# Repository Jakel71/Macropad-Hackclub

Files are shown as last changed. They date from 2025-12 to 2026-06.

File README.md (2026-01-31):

# Macropad-Hackclub
This is an Macro pad with 16 Buttons with background lighting. Its meant for simplicity and an everyday use. This is the reason why it will have shortcuts for Windows 11. You could adjust the Container of the PCB so that the lights are looking out, but scince I never saw this kind of LED I don't know how big the hole has to be.



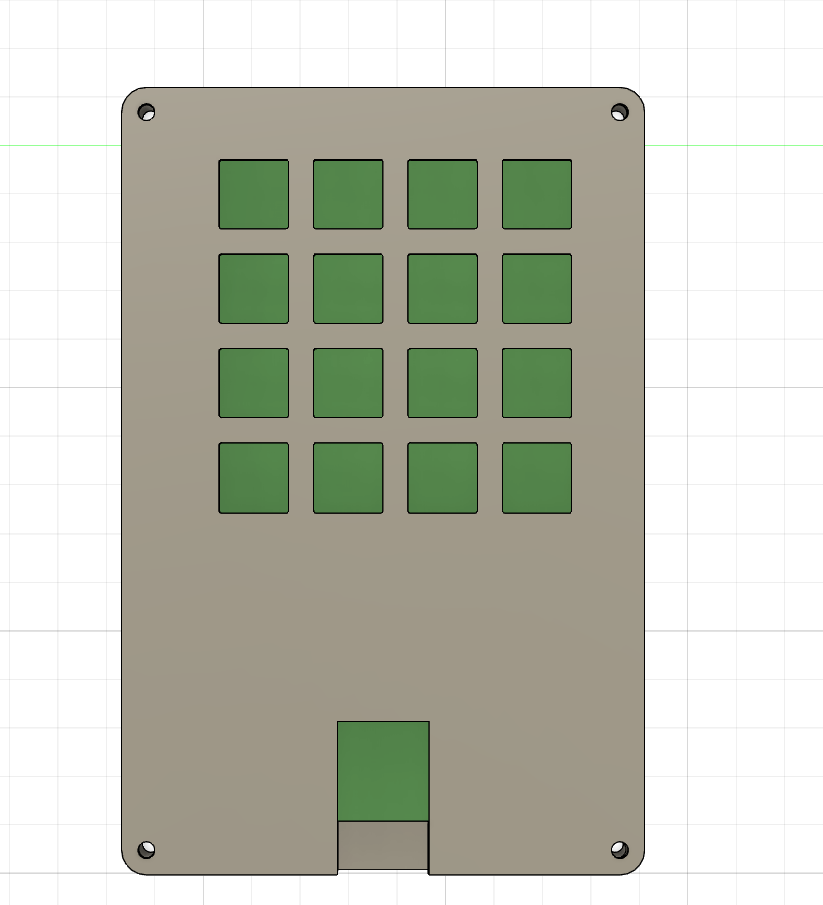
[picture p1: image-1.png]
over-all-box


In this picture you can see the Box in gray and the PCB in Green.

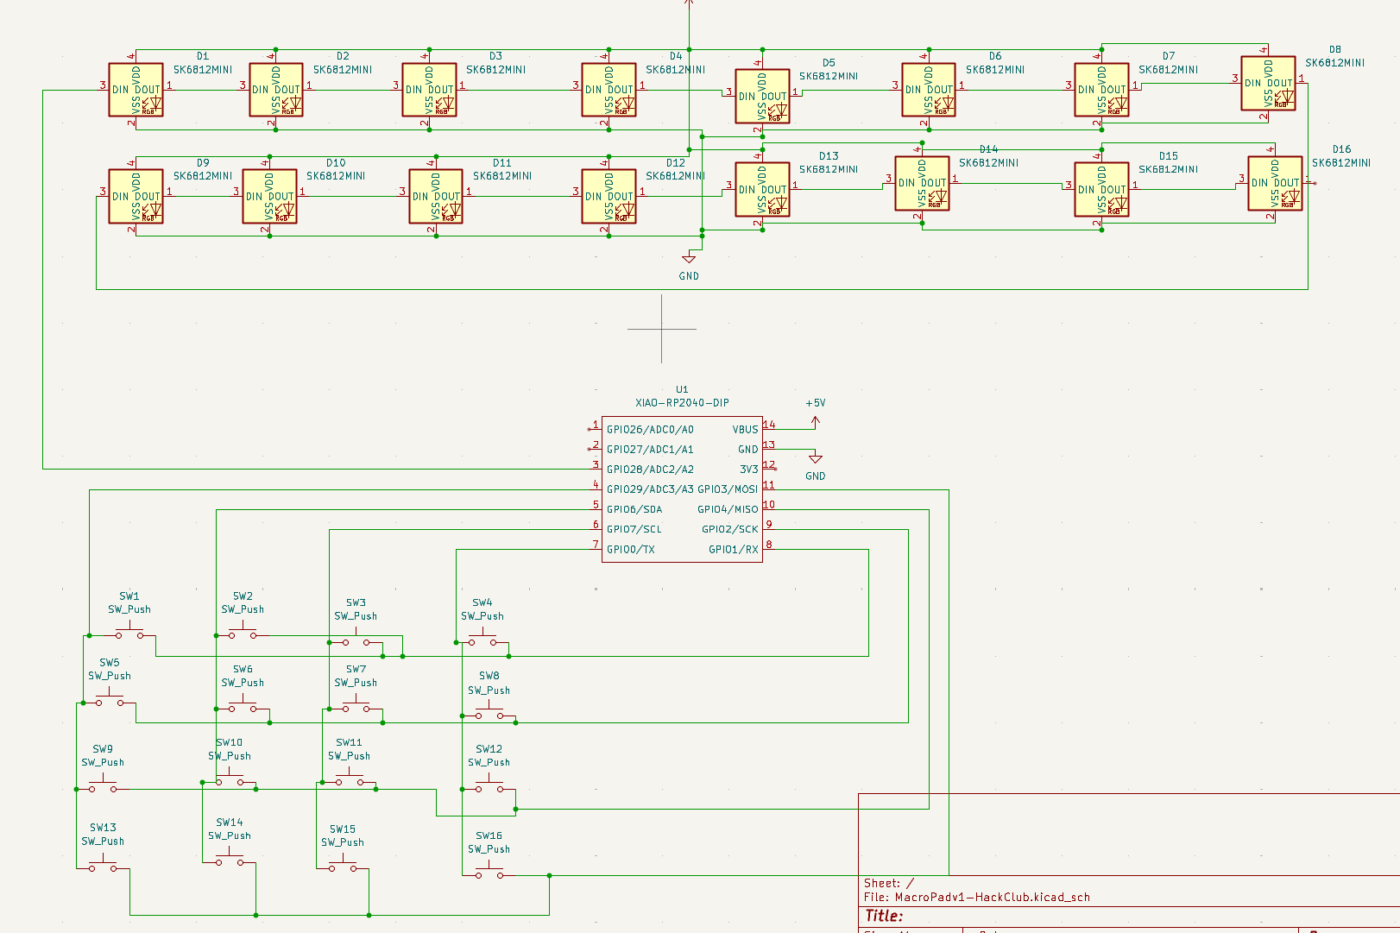
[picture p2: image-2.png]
shematics

Here you can see the shematics of th PCB. It could happen that the Analog pins won't allow Digitalinput, then you schould switsh to an other microcontroller (arduino/ESP) with more pins.

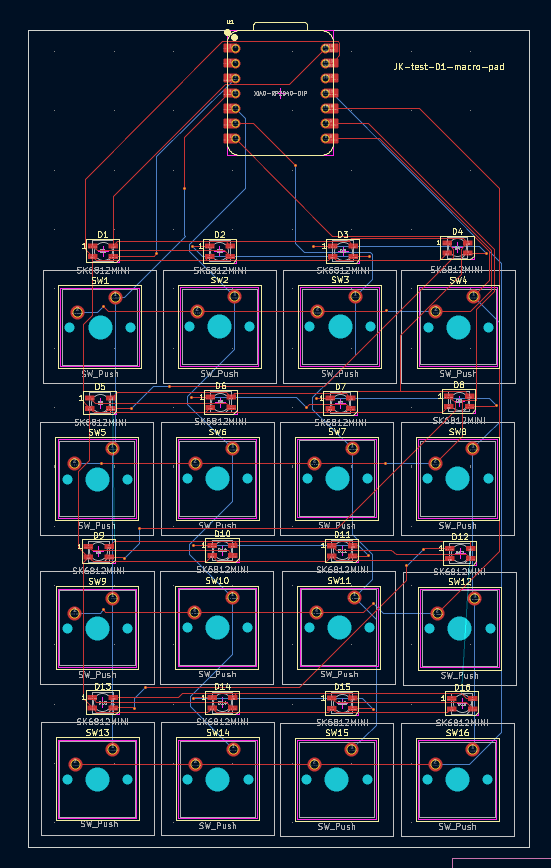
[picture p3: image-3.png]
PCB


Here you can see the PCB and all the components which you have to mount on it. The dimensions are 137x84.5mm this is more than the limit of 100mm in one dimension, but it would become very messy when you would pack it closer together.

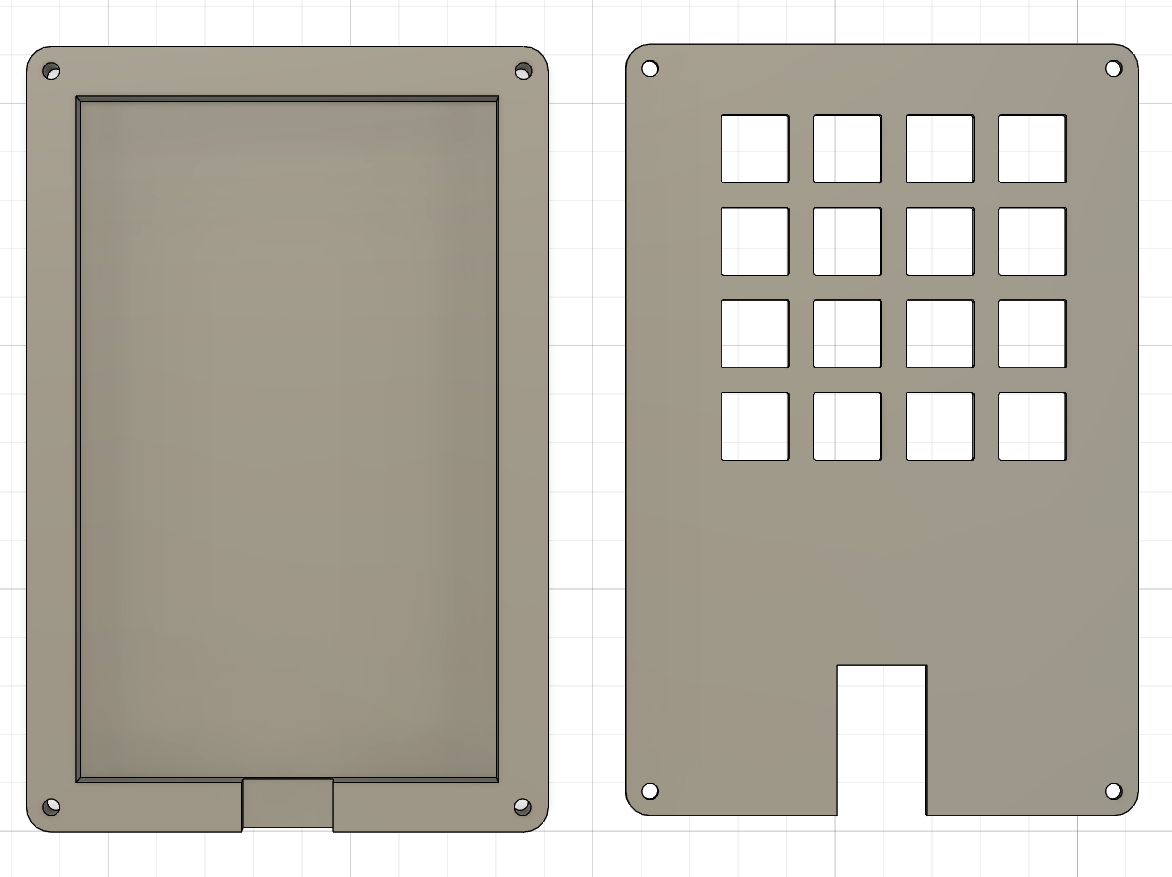
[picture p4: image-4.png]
caseparts

You can see here all the parts you need for the case just screew 4 screews in it and its ready to go.

BOM: (list of materials)
- 1 PCB
- 1 Case ( bittom + top part)
- M3x16mm screws
- M3x5mx4mm heatset inserts
- 16 Cherry MX 1 Keyboardbuttons
- 16 Keycaps
- 16 SK6812 MINI-E LEDs
- 1 Seeed XIAO RP2040

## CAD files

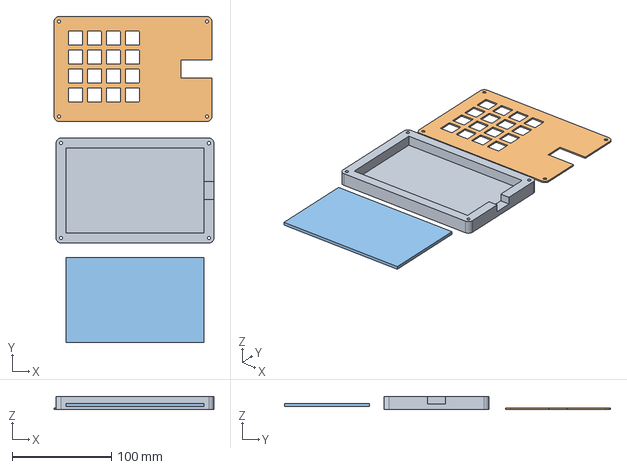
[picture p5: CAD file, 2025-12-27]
CAD/MacroPad-V_Hackclub v3.step
160.7 x 327.7 x 13.0 mm

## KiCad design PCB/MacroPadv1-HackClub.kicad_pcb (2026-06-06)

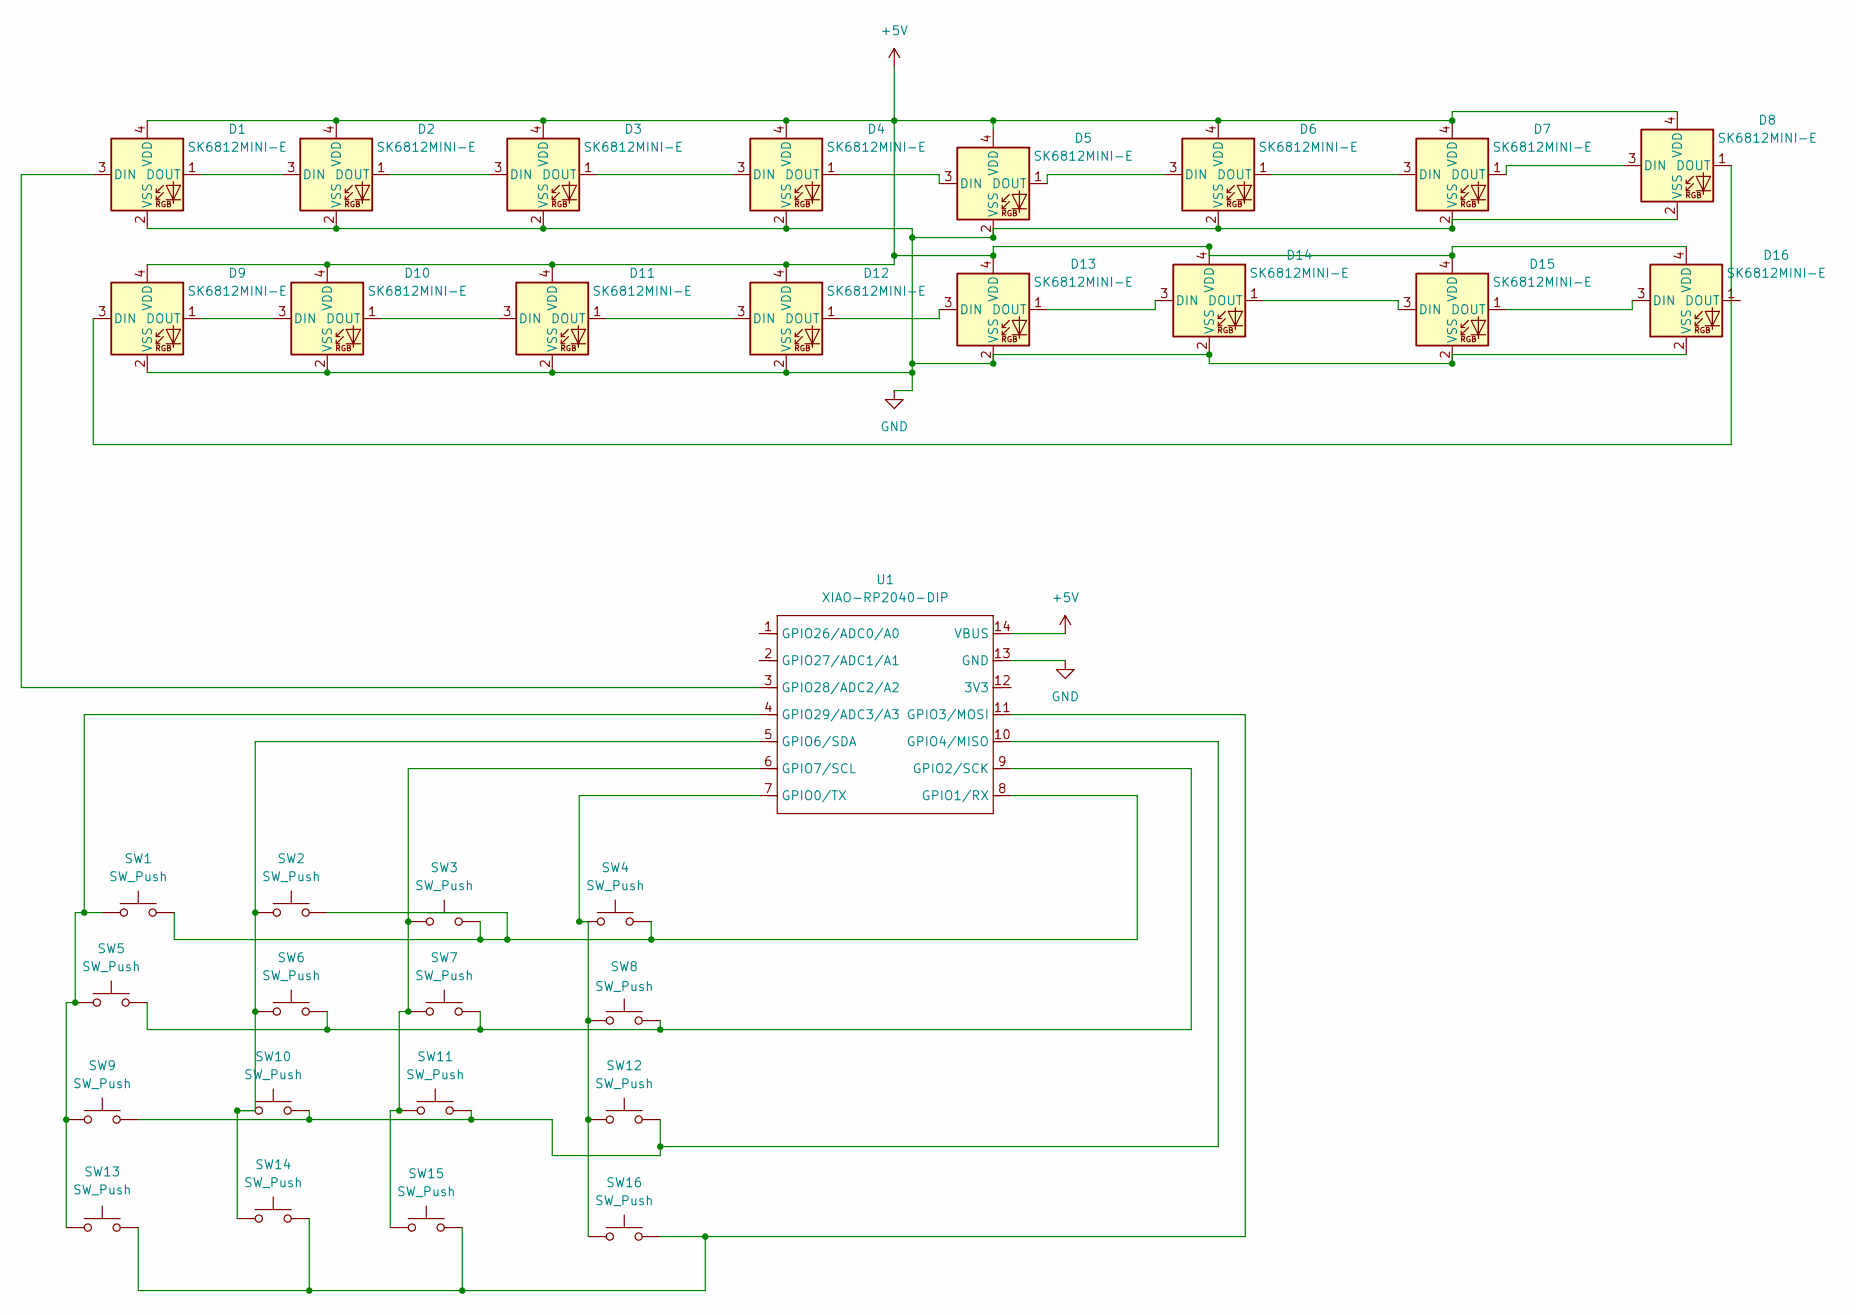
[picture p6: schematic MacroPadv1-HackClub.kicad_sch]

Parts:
D1, D2, D3, D4, D5, D6, D7, D8, D9, D10, D11, D12, D13, D14, D15, D16: SK6812MINI-E; MX_SK6812MINI-E
SW1, SW2, SW3, SW4, SW5, SW6, SW7, SW8, SW9, SW10, SW11, SW12, SW13, SW14, SW15, SW16: SW_Push; SW_Cherry_MX_1.00u_PCB
U1: XIAO-RP2040-DIP

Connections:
+5V: D1.4 (VDD), D2.4 (VDD), D3.4 (VDD), D4.4 (VDD), D5.4 (VDD), D6.4 (VDD), D7.4 (VDD), D8.4 (VDD), D9.4 (VDD), D10.4 (VDD), D11.4 (VDD), D12.4 (VDD), D13.4 (VDD), D14.4 (VDD), D15.4 (VDD), D16.4 (VDD), U1.14 (VBUS)
GND: D1.2 (VSS), D2.2 (VSS), D3.2 (VSS), D4.2 (VSS), D5.2 (VSS), D6.2 (VSS), D7.2 (VSS), D8.2 (VSS), D9.2 (VSS), D10.2 (VSS), D11.2 (VSS), D12.2 (VSS), D13.2 (VSS), D14.2 (VSS), D15.2 (VSS), D16.2 (VSS), U1.13 (GND)
unnamed: D1.3 (DIN), U1.3 (GPIO28/ADC2/A2)
unnamed: D1.1 (DOUT), D2.3 (DIN)
unnamed: D2.1 (DOUT), D3.3 (DIN)
unnamed: D3.1 (DOUT), D4.3 (DIN)
unnamed: D4.1 (DOUT), D5.3 (DIN)
unnamed: D5.1 (DOUT), D6.3 (DIN)
unnamed: D6.1 (DOUT), D7.3 (DIN)
unnamed: D7.1 (DOUT), D8.3 (DIN)
unnamed: D8.1 (DOUT), D9.3 (DIN)
unnamed: D9.1 (DOUT), D10.3 (DIN)
unnamed: D10.1 (DOUT), D11.3 (DIN)
unnamed: D11.1 (DOUT), D12.3 (DIN)
unnamed: D12.1 (DOUT), D13.3 (DIN)
unnamed: D13.1 (DOUT), D14.3 (DIN)
unnamed: D14.1 (DOUT), D15.3 (DIN)
unnamed: D15.1 (DOUT), D16.3 (DIN)
unnamed: SW4.1, SW8.1, SW12.1, SW16.1, U1.7 (GPIO0/TX)
unnamed: SW1.2, SW2.2, SW3.2, SW4.2, U1.8 (GPIO1/RX)
unnamed: SW5.2, SW6.2, SW7.2, SW8.2, U1.9 (GPIO2/SCK)
unnamed: SW13.2, SW14.2, SW15.2, SW16.2, U1.11 (GPIO3/MOSI)
unnamed: SW9.2, SW10.2, SW11.2, SW12.2, U1.10 (GPIO4/MISO)
unnamed: SW2.1, SW6.1, SW10.1, SW14.1, U1.5 (GPIO6/SDA)
unnamed: SW3.1, SW7.1, SW11.1, SW15.1, U1.6 (GPIO7/SCL)
unnamed: SW1.1, SW5.1, SW9.1, SW13.1, U1.4 (GPIO29/ADC3/A3)

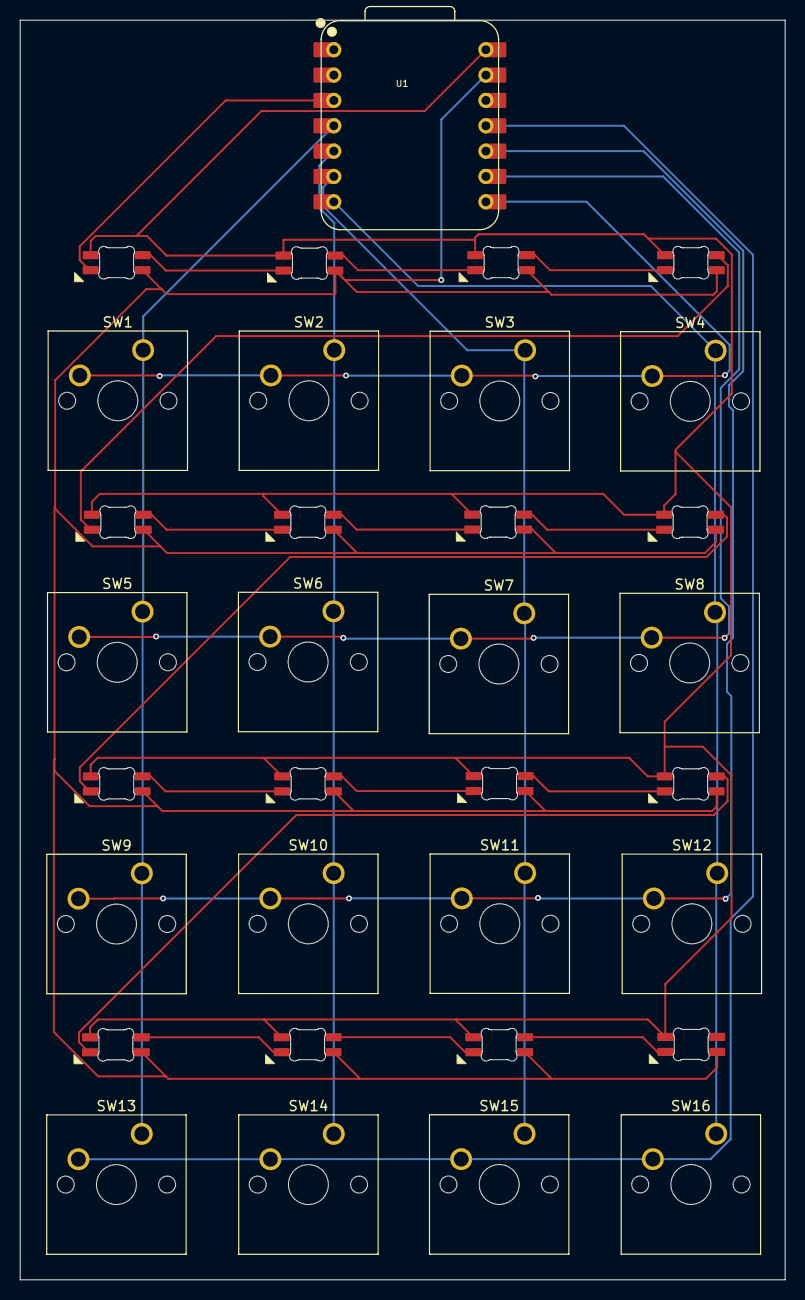
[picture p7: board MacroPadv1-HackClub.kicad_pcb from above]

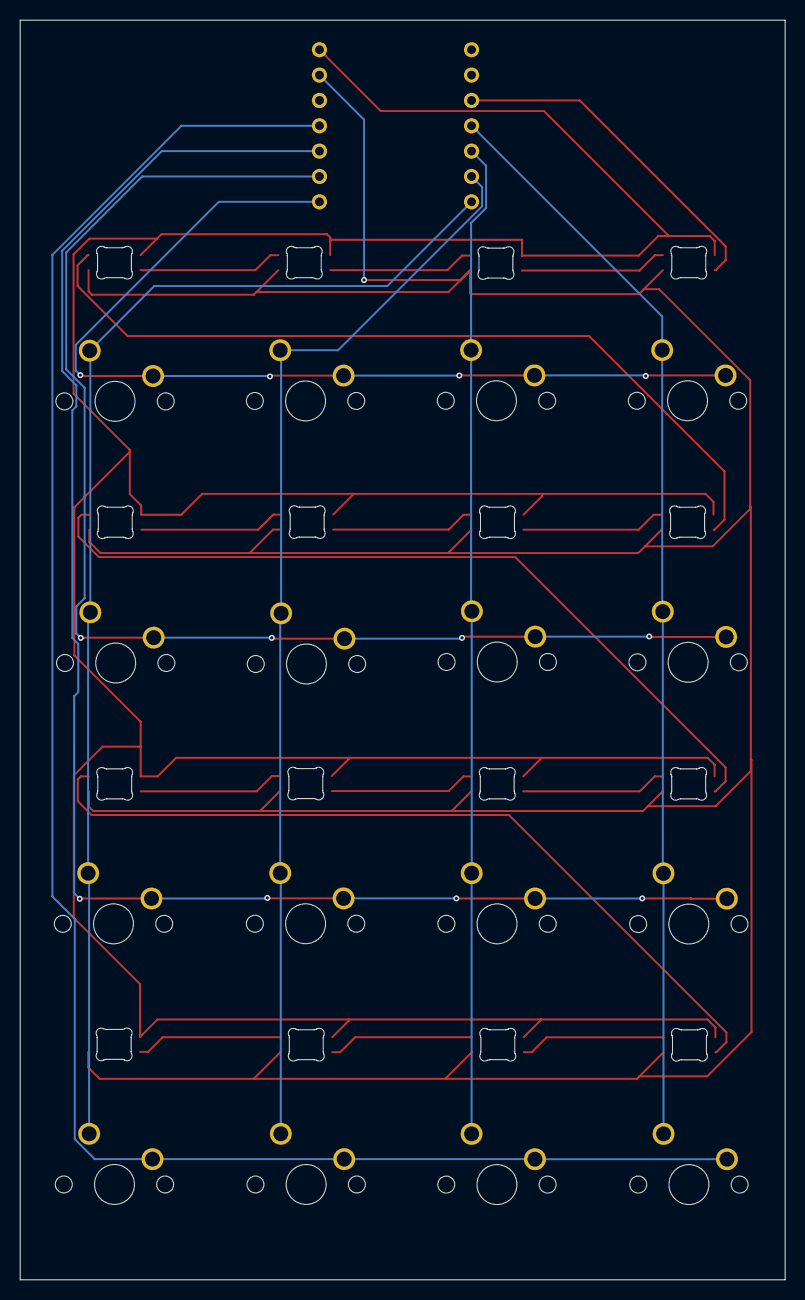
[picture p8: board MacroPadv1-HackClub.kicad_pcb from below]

Board: 2 copper layers, 76.7 x 126.2 mm, 33 parts (16 on the bottom side), 26 nets.

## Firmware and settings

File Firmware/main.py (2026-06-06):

import board
import digitalio
import time
import usb_hid
from adafruit_hid.keyboard import Keyboard
from adafruit_hid.keycode import Keycode
from adafruit_hid.consumer_control import ConsumerControl
from adafruit_hid.consumer_control_code import ConsumerControlCode
from adafruit_hid.keyboard_layout_us import KeyboardLayoutUS

import neopixel


# -----------------------
# KEYBOARD SETUP
# -----------------------
kbd = Keyboard(usb_hid.devices)
cc = ConsumerControl(usb_hid.devices)
layout = KeyboardLayoutUS(kbd)

# -----------------------
# RGB LED SETUP (16x SK6812 Mini on A2/GPIO28)
# -----------------------
pixel = neopixel.NeoPixel(board.A2, 16, brightness=0.2, auto_write=False)

# All LEDS are red = not ready
for i in range(16):
    pixel[i] = (255, 0, 0)
pixel.show()

# -----------------------
# MATRIX SETUP (4x4)
# -----------------------
# 
# ROWS (right side, Pins 8-11):
#   Pin 8  = GPIO1/RX    = board.RX  oder board.D1
#   Pin 9  = GPIO2/SCK   = board.SCK oder board.D2  
#   Pin 10 = GPIO4/MISO  = board.MISO oder board.D4
#   Pin 11 = GPIO3/MOSI  = board.MOSI oder board.D3
#
# COLUMNS (left side, Pins 4-7):
#   Pin 7 = GPIO0/TX   = board.TX  oder board.D0
#   Pin 6 = GPIO7/SCL  = board.SCL oder board.D7
#   Pin 5 = GPIO6/SDA  = board.SDA oder board.D6
#   Pin 4 = GPIO29/A3  = board.A3
#
# LEDs are on A2 (Pin 3)

row_pins = [board.RX, board.SCK, board.MISO, board.MOSI]  # Pins 8,9,10,11
col_pins = [board.A3, board.SDA, board.SCL, board.TX]     # Pins 4,5,6,7

# Setup Rows as Output (HIGH = deactivated)
rows = []
for pin in row_pins:
    row = digitalio.DigitalInOut(pin)
    row.direction = digitalio.Direction.OUTPUT
    row.value = True  # HIGH = inaktiv
    rows.append(row)

# Setup Columns as Input with Pull-Up
cols = []
for pin in col_pins:
    col = digitalio.DigitalInOut(pin)
    col.direction = digitalio.Direction.INPUT
    col.pull = digitalio.Pull.UP
    cols.append(col)

# -----------------------
# MACRO FUNKTIONS
# -----------------------
def send_macro(keys, modifiers=[]):
    """Sendet eine Tastenkombination"""
    for mod in modifiers:
        kbd.press(mod)
    time.sleep(0.01)
    
    for key in keys:
        kbd.press(key)
        time.sleep(0.01)
        kbd.release(key)
        time.sleep(0.01)
    
    for mod in modifiers:
        kbd.release(mod)

# -----------------------
# KEYMAP DEFINITION
# -----------------------
def key_0():  # Taste 1 // Rickroll
    send_macro([Keycode.R], [Keycode.GUI])  # WIN+R
    time.sleep(0.1)
    layout.write('cmd\n')
    time.sleep(1)
    layout.write('curl ASCII.live&can/zou/hear/me\n')

def key_1():  # Taste 2
    send_macro([Keycode.L], [Keycode.GUI])  # WIN+L // lock screen

def key_2():  # Taste 3
    send_macro([Keycode.F4], [Keycode.ALT])  # ALT+F4 //end current window

def key_3():  # Taste 4
    send_macro([Keycode.D], [Keycode.GUI])  # WIN+D // show desktop

def key_4():  # Taste 5
    send_macro([Keycode.TAB], [Keycode.ALT])  # ALT+TAB // switch window

def key_5():  # Taste 6
    send_macro([Keycode.P], [Keycode.GUI])  # WIN+P // monitor settings

def key_6():  # Taste 7
    send_macro([Keycode.E], [Keycode.GUI])  # WIN+E // open file explorer

def key_7():  # Taste 8
    send_macro([Keycode.LEFT_SHIFT],[Keycode.LEFT_CONTROL], [Keycode.ESCAPE])  # open Taskmanager with STRG+SHIFT+ESC

def key_8():  # Taste 9
    send_macro([Keycode.S], [Keycode.GUI, Keycode.SHIFT])  # WIN+SHIFT+S // Screenshot

def key_9():  # Taste 10
    send_macro([Keycode.I], [Keycode.GUI])  # WIN+I // open settings

def key_10():  # Taste 11
    send_macro([Keycode.K], [Keycode.GUI])  # WIN+K // open connect menu for wireless displays

def key_11():  # Taste 12
    send_macro([Keycode.R], [Keycode.GUI])  # WIN+R // open run dialog

def key_12():  # Taste 13 - Media Play/Pause
    cc.send(ConsumerControlCode.PLAY_PAUSE)

def key_13():  # Taste 14 - Mute
    cc.send(ConsumerControlCode.MUTE)

def key_14():  # Taste 15 - Volume Down
    cc.send(ConsumerControlCode.VOLUME_DECREMENT)

def key_15():  # Taste 16 - Volume Up
    cc.send(ConsumerControlCode.VOLUME_INCREMENT)

# Keymap Array
keymap = [
    [key_0,  key_1,  key_2,  key_3],
    [key_4,  key_5,  key_6,  key_7],
    [key_8,  key_9,  key_10, key_11],
    [key_12, key_13, key_14, key_15]
]

# -----------------------
# LED COLORS
# -----------------------
COLOR_IDLE = (0, 50, 255)      # Blau - Idle
COLOR_PRESSED = (0, 255, 0)    # Grün - Gedrückt

# -----------------------
# DEBOUNCE & STATE
# -----------------------
last_state = [[False for _ in range(4)] for _ in range(4)]
debounce_time = 0.02

# -----------------------
# MAIN LOOP
# -----------------------
print("=== 4x4 Macropad gestartet ===")
print("Rows: RX, SCK, MISO, MOSI (Pins 8-11)")
print("Cols: A3, SDA, SCL, TX (Pins 4,5,6,7)")
print("LEDs: A2 (Pin 3)")

# All LEDS on Blue = ready
for i in range(16):
    pixel[i] = COLOR_IDLE
pixel.show()

while True:
    # Scann Matrix
    for row_idx, row in enumerate(rows):
        # Active Row (LOW = activ)
        row.value = False
        time.sleep(0.005)  # 5ms Debounce
        
        # read Columns
        for col_idx, col in enumerate(cols):
            current_state = not col.value  # inverted for pull-up
            
            # calculate LED Index (left to right)
            led_idx = row_idx * 4 + col_idx
            
            # Check for state change
            if current_state != last_state[row_idx][col_idx]:
                if current_state:  # Taste gedrückt
                    print(f"Taste {led_idx + 1} gedrückt")
                    
                    # LED green
                    pixel[led_idx] = COLOR_PRESSED
                    pixel.show()
                    
                    # do action
                    keymap[row_idx][col_idx]()
                    
                    time.sleep(debounce_time)
                    
                else:  # button no longer pressed
                    # LED back to blue
                    pixel[led_idx] = COLOR_IDLE
                    pixel.show()
                
                last_state[row_idx][col_idx] = current_state
        
        # Deactivate Row (HIGH = inactiv)
        row.value = True
        time.sleep(0.001)  # 1ms Pause between Rows
    
    time.sleep(1)  # 10ms Pause between Scans

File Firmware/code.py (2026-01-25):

import board
import digitalio
import time

print("\n" + "="*50)
print("MATRIX DIAGNOSE - Finde die richtige Pin-Zuordnung")
print("="*50)

# Aktuelle Pin-Konfiguration
row_pins = [board.RX, board.SCK, board.MISO, board.MOSI]
col_pins = [board.A3, board.SDA, board.SCL, board.TX]

row_names = ["RX/P8", "SCK/P9", "MISO/P10", "MOSI/P11"]
col_names = ["A3/P4", "SDA/P5", "SCL/P6", "TX/P7"]

print("\nAktuelle Konfiguration:")
print("ROWS:", ", ".join(row_names))
print("COLS:", ", ".join(col_names))
print()

# Setup Rows als Output (HIGH = deaktiviert)
rows = []
for i, pin in enumerate(row_pins):
    row = digitalio.DigitalInOut(pin)
    row.direction = digitalio.Direction.OUTPUT
    row.value = True  # HIGH = inaktiv
    rows.append(row)
    print(f"✓ Row {i} ({row_names[i]}): HIGH (inaktiv)")

# Setup Columns als Input mit Pull-Up
cols = []
for i, pin in enumerate(col_pins):
    col = digitalio.DigitalInOut(pin)
    col.direction = digitalio.Direction.INPUT
    col.pull = digitalio.Pull.UP
    cols.append(col)
    print(f"✓ Col {i} ({col_names[i]}): INPUT Pull-UP")

print("\n" + "="*50)
print("LIVE MATRIX SCAN")
print("="*50)
print("\nDrücke EINE Taste und schau, welche erkannt wird!")
print("Format: [Row,Col] = Position in Matrix")
print("STRG+C zum Beenden\n")

# Tracking
last_state = [[False for _ in range(4)] for _ in range(4)]

try:
    while True:
        active_keys = []
        
        # Scanne jede Row
        for row_idx in range(4):
            # Aktiviere nur diese Row (LOW)
            rows[row_idx].value = False
            time.sleep(0.005)  # 5ms Stabilisierung
            
            # Lese alle Columns
            for col_idx in range(4):
                # Pull-Up invertiert: LOW = gedrückt
                is_pressed = not cols[col_idx].value
                
                if is_pressed:
                    key_num = row_idx * 4 + col_idx
                    active_keys.append((row_idx, col_idx, key_num))
            
            # Deaktiviere Row wieder (HIGH)
            rows[row_idx].value = True
            time.sleep(0.001)  # 1ms Pause
        
        # Zeige aktive Tasten
        if active_keys:
            print("\n--- TASTEN GEDRÜCKT ---")
            for row, col, num in active_keys:
                print(f"  [Row {row}, Col {col}] = Taste {num} ({row_names[row]} + {col_names[col]})")
            time.sleep(0.2)  # Debounce
        
        time.sleep(0.01)

except KeyboardInterrupt:
    print("\n\nDiagnose beendet\n")
    
    # Cleanup
    for row in rows:
        row.deinit()
    for col in cols:
        col.deinit()

print("="*50)
print("AUSWERTUNG:")
print("="*50)
print("\nDrücke jede Taste einzeln und notiere:")
print("  - Welche Position wird erkannt?")
print("  - Werden mehrere Positionen erkannt?")
print("  - Ist die Reihenfolge konsistent?")
print("\nDann können wir die Pins richtig zuordnen!")

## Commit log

2025-12-27 Add BOM section with list of materials
    Added a Bill of Materials (BOM) section to the README.
2025-12-27 Revise BOM with detailed component specifications
    Updated BOM with specific hardware components.
2026-01-30 Code+Mini-E
    Added Code and swaped LEDS for the right type
    [MacroPadv1-HackClub-B_Cu.gbr, MacroPadv1-HackClub-B_Mask.gbr, MacroPadv1-HackClub-B_Paste.gbr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]
2026-01-31 Pcb rerouting
    [MacroPadv1-HackClub-B_Cu.gbr, MacroPadv1-HackClub-B_Mask.gbr, MacroPadv1-HackClub-B_Paste.gbr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]
2026-06-06 comments added and redesign on LED startup color and 2 Keys rewritten to be more usefull
    [MacroPadv1-HackClub-B_Cu.gbr, MacroPadv1-HackClub-B_Mask.gbr, MacroPadv1-HackClub-B_Paste.gbr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]
